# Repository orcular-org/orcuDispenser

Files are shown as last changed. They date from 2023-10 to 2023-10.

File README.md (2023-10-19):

# orcuDispenser

## Liquid dispenser from recycled plastics

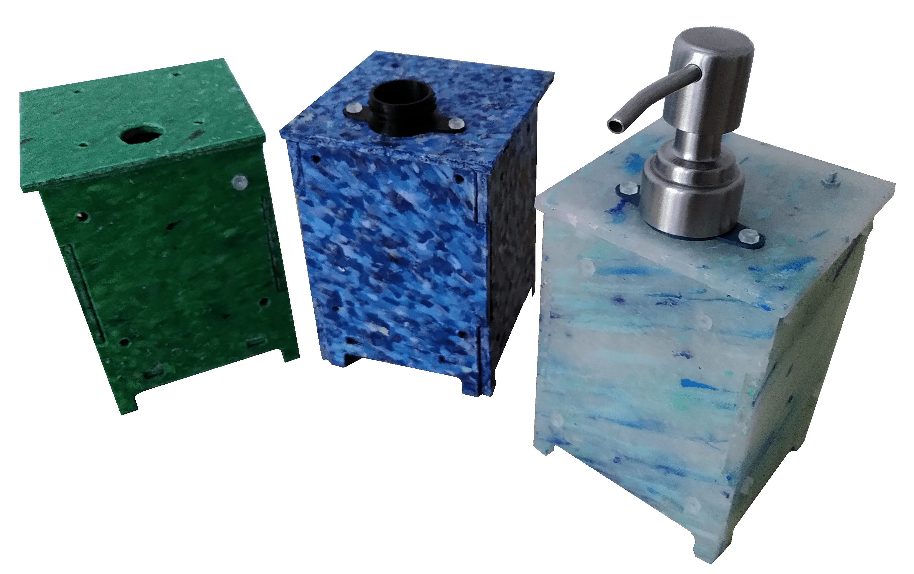
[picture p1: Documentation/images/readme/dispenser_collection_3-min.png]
 

The orcuDispenser (short for "[Orcular](#about-the-orcular-project) Dispenser") is an open-source dispenser made from recycled plastics. The main features are:
- For soap or other liquids like dishwashing liquid, shampoo or body wash
- Made from recycled plastics ([Precious Plastic](https://preciousplastic.com/) sheets)
- Laser-cut parts
- 3D printed parts
- Circular design
  - Easy to repair & upgrade
  - Designed for disassembly
  - All parts recyclebale (except for the pump, depends on the product)
- [Open-source hardware](#license)
- Designed in [FreeCAD](https://www.freecad.org/) (open-source software)
  - CAD file accessible in this repository
  - Parametric design (other sizes are easy to generate)

## 3D view

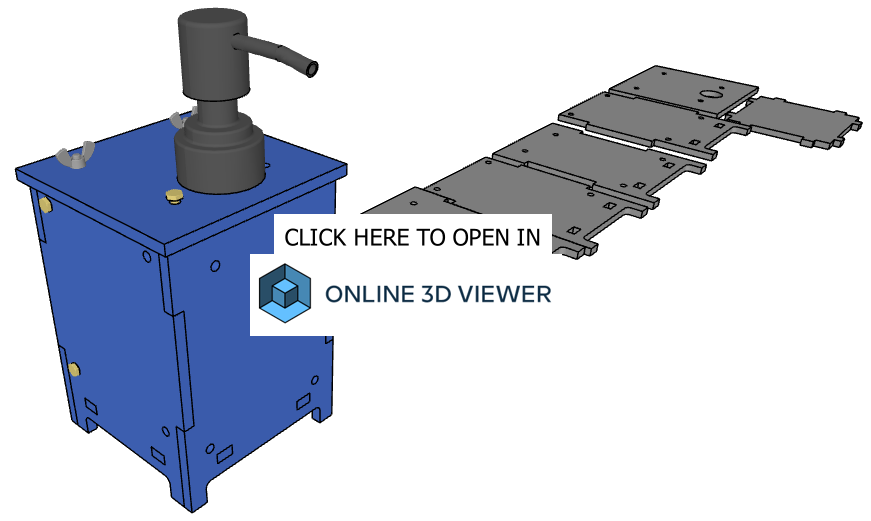
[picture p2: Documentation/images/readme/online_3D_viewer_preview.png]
[](https://3dviewer.net/embed.html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,-245.07455,234.76594,244.75676,161.15922,-120.84555,0.00000,-0.00000,1.00000,45.00000$cameramode=perspective$envsettings=fishermans_bastion,off$backgroundcolor=255,255,255,255$defaultcolor=200,200,200$edgesettings=on,0,0,0,84)

- Please be patient and wait about a minute to load the online 3D view

Controls:
- On computer: Use the left mouse button to rotate, the right mouse button to pan and the mouse wheel to zoom
- On smartphones: Swipe to rotate, use two fingers to zoom and pan 

- Alternative 3D view with more tools [here](https://3dviewer.net/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)
  - Click "Set Z axis as up vector" for better display a 
  - You can hide/show parts and groups on the left-hand side
  - For a complete view of the 3D file, download the [CAD file](CAD) and open it in [FreeCAD](https://www.freecad.org/)
 
## Building instructions
 
For making and building instructions, see the [documentation](Documentation/Introduction.md)

or go directly to:

- 🛒 [Shopping list](Documentation/Shopping_list.md)
- ♻️ [Making sheets from recycled plastics](Documentation/Making_sheets.md)
- 🖨️ [3D printing](Documentation/3D_printing.md)
- 🔫 Laser cutting *(coming soon)*
- 🛠️ [Assembly](Documentation/Assembly.md)
- 🔼 Modding and upgrades *(coming soon)*

## About the Orcular project
The orcuDispenser is part of the Orcular project - https://www.orcular.org

"Orcular" stands for **O**pen Source + Ci**rcular** Economy

The project is about design concepts for locally recyclable products - for a constantly growing open source product library and the development of inner-city production.

Most components can be recycled into new parts - all within one city.
Recyclable plastic parts from the laser cutter, 3D printer and CNC mill, supplemented by standard parts.

## License

The orcuDispenser hardware design, CAD files, BOM, and relative files are are released under the following open source license:

- [CERN Open Hardware Licence Version 2 Weakly Reciprocal - CERN-OHL-W](https://cern-ohl.web.cern.ch/)

The orcuDispenser documentation, assembly manual, pictures and presentation text of this repository are released under the following license:

- [Creative-Commons-Attribution-ShareAlike 4.0 International - CC BY-SA 4.0](http://creativecommons.org/licenses/by-sa/4.0/)

**Author:** Oskar Lidtke, https://github.com/orcular-org/

<br />Except where otherwise noted, this work is licensed under a <a rel="license" href="http://creativecommons.org/licenses/by-sa/4.0/">Creative Commons Attribution-ShareAlike 4.0 International License (CC BY-SA 4.0)</a>.

See best practices for [attribution](https://wiki.creativecommons.org/wiki/Best_practices_for_attribution) and [marking your own work](https://wiki.creativecommons.org/wiki/Marking_your_work_with_a_CC_license) with a CC license.

<p align="left">
<i> <sub> Open Source Hardware logo, <a href="https://creativecommons.org/licenses/by-sa/4.0/">CC BY-SA</a> - <a href="https://www.oshwa.org/open-source-hardware-logo/">Source</a> </sub></i>
</p>



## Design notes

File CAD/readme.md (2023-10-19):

**Recent version: 1.0** - released on October 19, 2023.

The CAD model was designed in FreeCAD. You can download this free and open-source software on https://www.freecad.org

For modding instructions and changing parameters in the CAD file, see the [documentation](../Documentation/Introduction.md), section **Modding and upgrades**.

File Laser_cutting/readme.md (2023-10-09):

This folder contains the laser cutting vector graphics file. For laser cutting instructions, see the [documentation](../Documentation/Introduction.md), section **Laser cutting**.

This SVG vector graphics file was created for 4.7 mm thick sheets. It may also work with uneven sheets within the tolerance range of about 4.2 to 5.2 mm (testing needed).

For instructions about how to generate vector graphics for other sheet thicknesses, see the [documentation](../Documentation/Introduction.md), section **Modding and upgrades**.

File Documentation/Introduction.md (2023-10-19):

> Back to [main page (readme)](../README.md)

# orcuDispenser documentation

## Introduction

> Add introduction text

- 🛒 [Shopping list](Shopping_list.md)
- ♻️ [Making sheets from recycled plastics](Making_sheets.md)
- 🖨️ [3D printing](3D_printing.md)
- 🔫 Laser cutting *(coming soon)*
- 🛠️ [Assembly](Assembly.md)
- 🔼 Modding and upgrades *(coming soon)*

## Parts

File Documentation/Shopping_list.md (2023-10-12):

> Back to [documentation introduction](Introduction.md)

# Shopping list

## Standard parts

Here is a list of standard parts:

| Quantity  | Part | Material | Standard | Shop link (suggestion) |
|---|---|---|---|---|
| 16 | M3 x 10 screw | PP (Polypropylene) | DIN 933/931 / DIN EN ISO 4017 | [Link](https://www.kunststoffschraube.de/product_info.php?products_id=4129) |
| 16 | M3 nut | PP (Polypropylene) | DIN 555/934 / DIN EN ISO 4032 | [Link](https://www.kunststoffschraube.de/product_info.php?products_id=4185) |
| 2 | M3 x 16 screw | Stainless steel | DIN 933 / DIN EN ISO 4017 | [Link](https://www.schraubenking-shop.de/M3-x-16mm-Sechskantschrauben-DIN-933-Vollgewinde-Edelstahl-A2-P000418) |
| 2 | M3 nut | Stainless steel | DIN 934 / DIN EN ISO 4032 | [Link](https://www.schraubenking-shop.de/M3-Sechskantmuttern-DIN-934-Edelstahl-A2-P000447) |
| 2 | M3 wingnut | Stainless steel | DIN 315 or similar | [Link](https://www.schraubenking-shop.de/M3-Fluegelmutter-amerik-Form-Edelstahl-A2-P004284) |

<table>
  <tr>
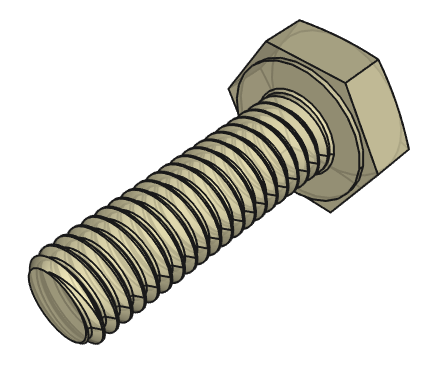
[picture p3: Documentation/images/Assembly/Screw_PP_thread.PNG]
    <td></td>
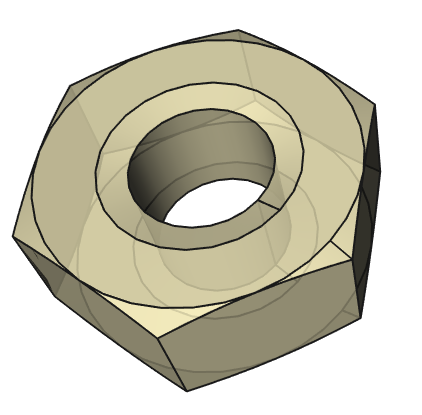
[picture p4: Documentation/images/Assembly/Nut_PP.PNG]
    <td></td>    
  </tr>
  <tr>
    <td>M3 x 10 screw <br> Polypropylene (PP) <br> 18 pieces</td></td>
    <td>M3 nut <br> Polypropylene (PP) <br> 18 pieces</td>
  </tr>
</table>

<table>
  <tr>
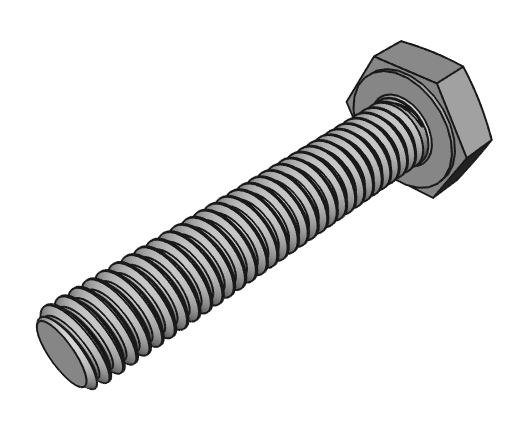
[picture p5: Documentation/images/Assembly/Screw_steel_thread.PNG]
    <td></td>
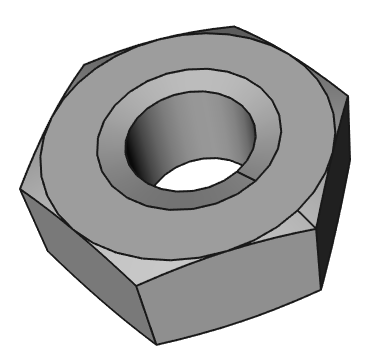
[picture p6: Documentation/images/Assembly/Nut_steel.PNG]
    <td></td>
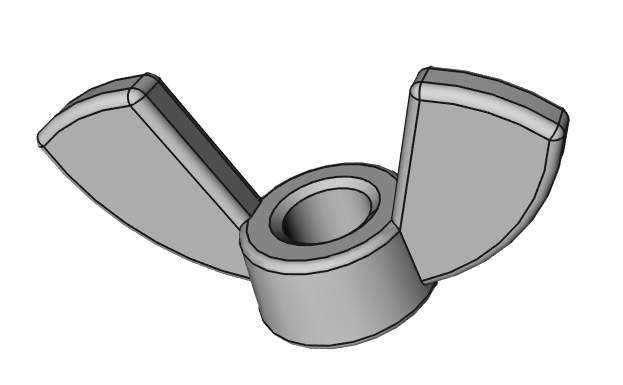
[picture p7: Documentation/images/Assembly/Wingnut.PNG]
    <td></td>
  </tr>
  <tr>
    <td>M3 x 16 screw <br> Stainless steel <br> 2 pieces</td>
    <td>M3 nut <br> Stainless steel <br> 2 pieces</td>
    <td>M3 wingnut <br> Stainless steel <br> 2 pieces</td>
  </tr>
</table>

- Most of the screws and nuts are suggested to be made from Polypropylene (PP). The reasons are:
  - PP is lighter than steel, which makes the whole dispenser lighter
  - PP is recyclebale in plastic recycling machines and PP is the same material that the sheets are made from. This way, broken or used PP screws and nuts can be recycled and new sheets can be made from the PP material.
  - PP parts have a nice translucent look, they are not so visible and don't stand out too much
  - But you can still use steel screws and nuts instead of PP if you like

- The two M3 x 16 screws, nuts and wingnuts in the lid should be stainless steel. The reasons are:
  - These wingnuts have to be undone every time you want to refill your dispenser. Plastic screws and nuts tend to wear off and break quickly, so steel parts are recommended
  - Stainless steel is recommended as these parts may get in contact with water a lot (by splashes from the water tap or wet hands)
 
- All screws should be hex head screws so that they fit into the pockets of the 3D printed parts

## Other parts

Here is a list of other parts:

| Quantity  | Part | Shop link (suggestion) |
|---|---|---|
| 1 | Soap dispenser pump | [Link](https://www.amazon.de/Ertisa-Edelstahl-seifenspender-flüssiges-Badezimmer/dp/B086PS4G4Q/) |

- If the suggested pump is not available, get a similar one or reuse a pump from another dispenser. Just make sure that it fits on the thread.

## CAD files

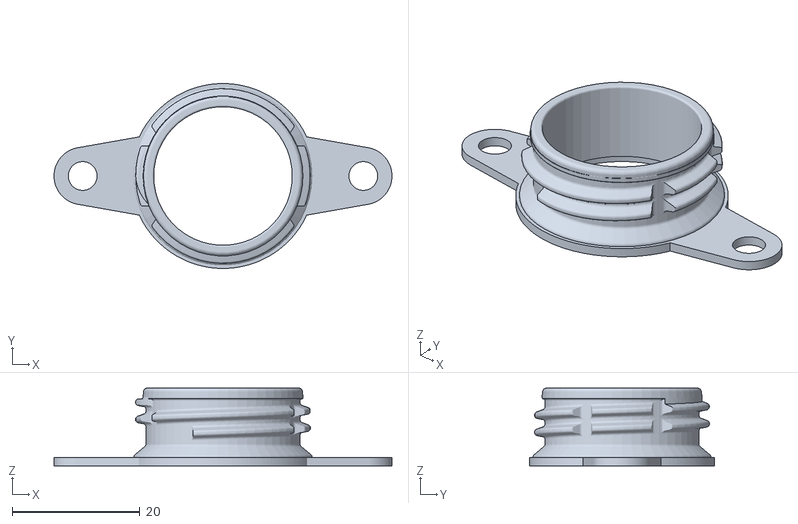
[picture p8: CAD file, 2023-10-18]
3D_printing/Adapter_for_pump.stl
53.0 x 29.0 x 12.2

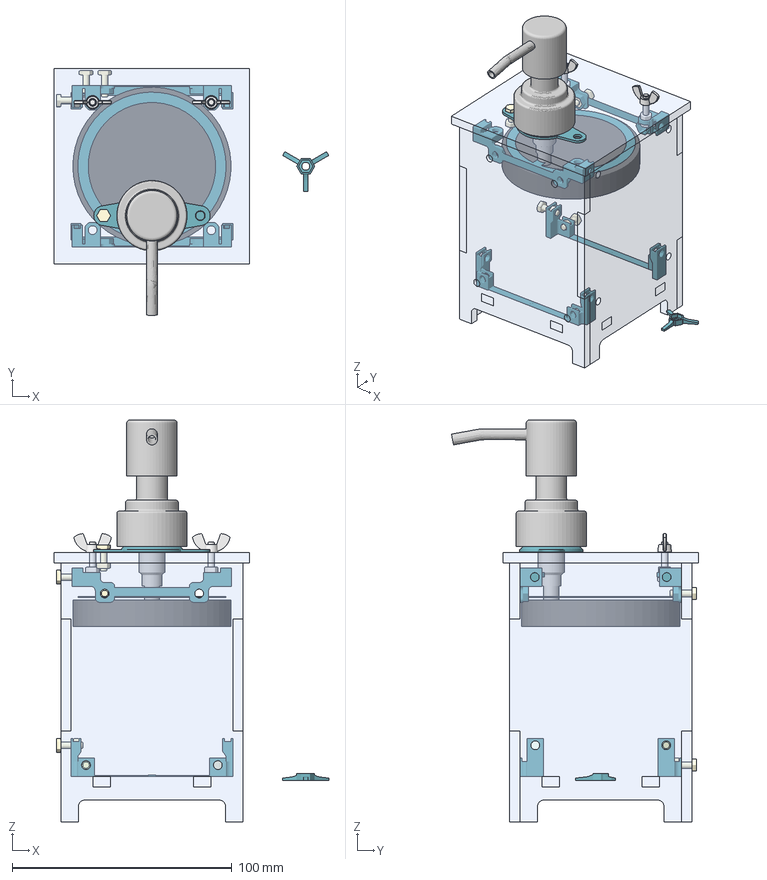
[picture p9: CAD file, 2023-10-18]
CAD/orcuDispenser_v_1_0.FCStd
125.0 x 112.5 x 183.0 mm
Bottom
Front
Back
Side_Left
Side_Right (clone)
Lid
3DP_Angle_bracket_Bottom
3DP_Angle_bracket_Bottom (Mirror #1)
Connector_bottom
3DP_Angle_bracket_Top
3DP_Angle_bracket_Top (Mirror #2)
Connector_top
3DP_Wrench
3DP_Drilling_template
M3x10-Screw
M3-Nut
M3x10-Screw001
M3x10-Screw002
M3x10-Screw003
M3-Nut006
M3-Nut007
M4-Nut001
M3x10-Screw004
M3-Nut005
M3_screw_right
M3_nut_right
Wingnut_right
Pump
Pipe
Jar (0,2 L)
Jar_Lid
3DP_Adapter_for_pump
Angle_bracket_bottom
Angle_bracket_top

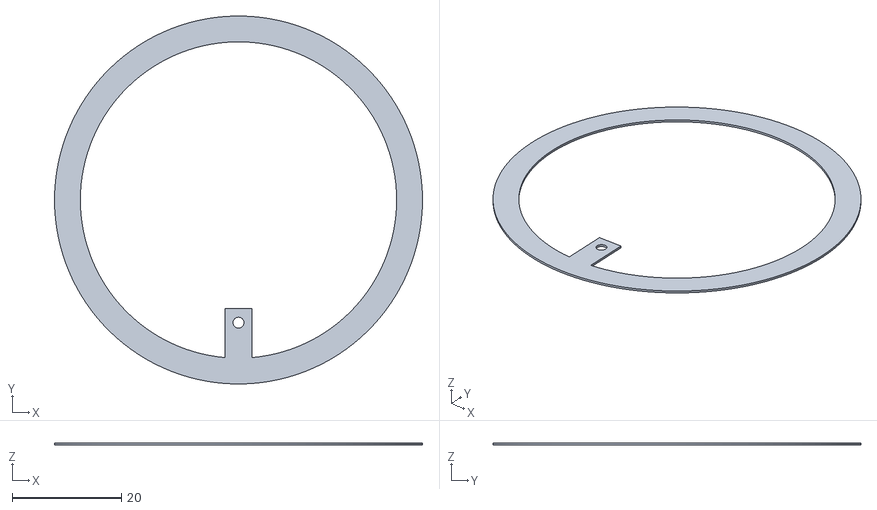
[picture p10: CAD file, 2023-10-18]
3D_printing/Drilling_template.stl
67.5 x 67.5 x 0.4

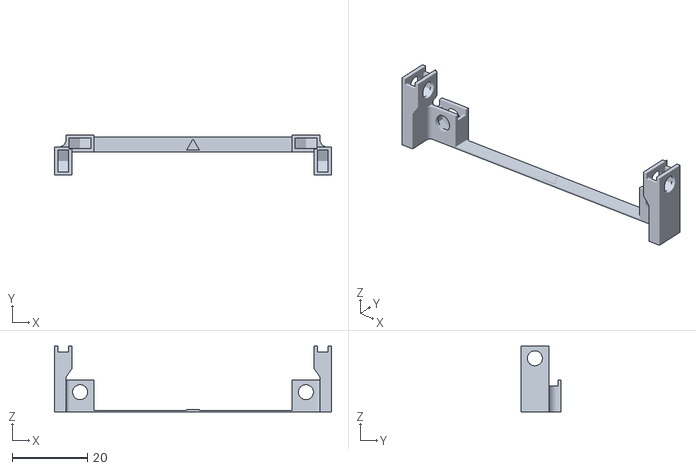
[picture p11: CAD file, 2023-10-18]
3D_printing/Angle_bracket_bottom.stl
73.6 x 10.8 x 17.4

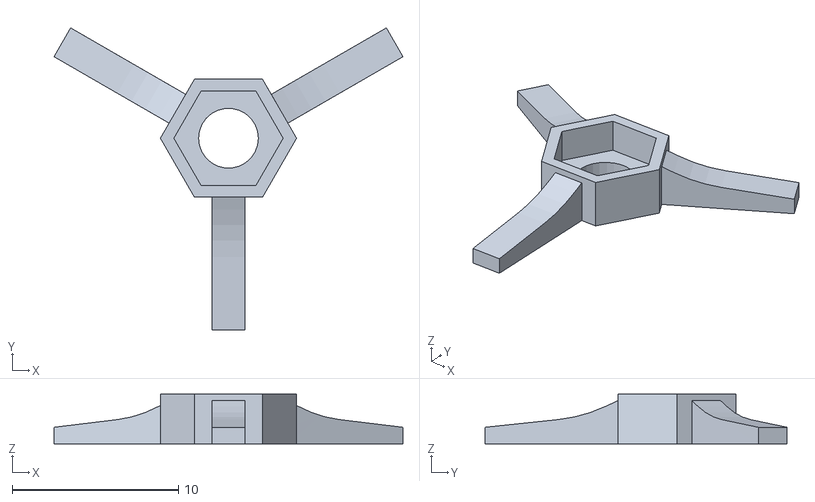
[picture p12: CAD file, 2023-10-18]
3D_printing/Wrench.stl
21.0 x 18.2 x 3.00

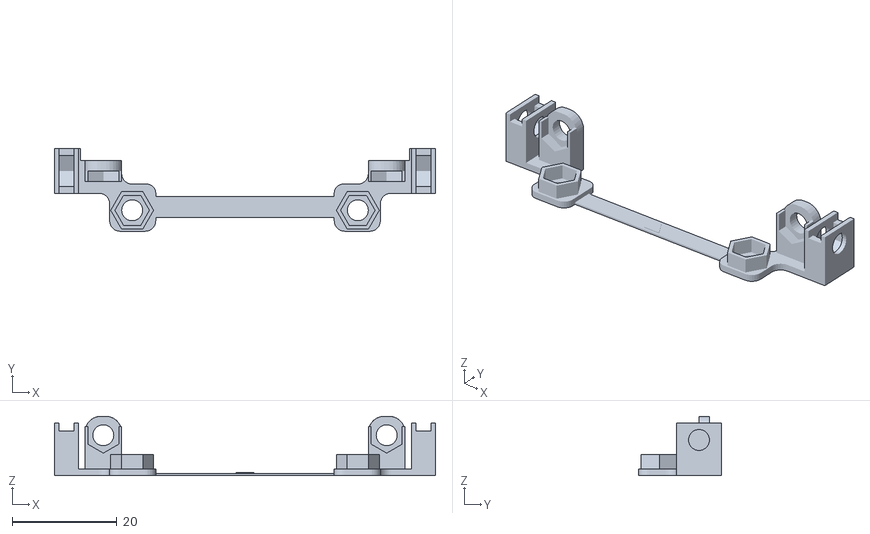
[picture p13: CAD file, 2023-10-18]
3D_printing/Angle_bracket_top.stl
72.6 x 15.7 x 11.3

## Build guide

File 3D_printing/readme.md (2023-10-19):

This folder contains all 3D printing STL files. For printing instructions, see the [documentation](../Documentation/Introduction.md), section [3D printing](../Documentation/3D_printing.md).

You can click on any STL file to see a 3D view (GitHub feature).

"Adapter_for_pump.stl" was created using "Pop Bottle Thread" from [this Thingiverse file](https://www.thingiverse.com/thing:3527583) (license: CC0 / public domain, no attribution required).

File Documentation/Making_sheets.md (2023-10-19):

> Back to [documentation introduction](Introduction.md)

# Making sheets from recycled plastics

Here are some instructions for making sheets from recycled plastic using [Precious Plastic](https://preciousplastic.com/) methods.

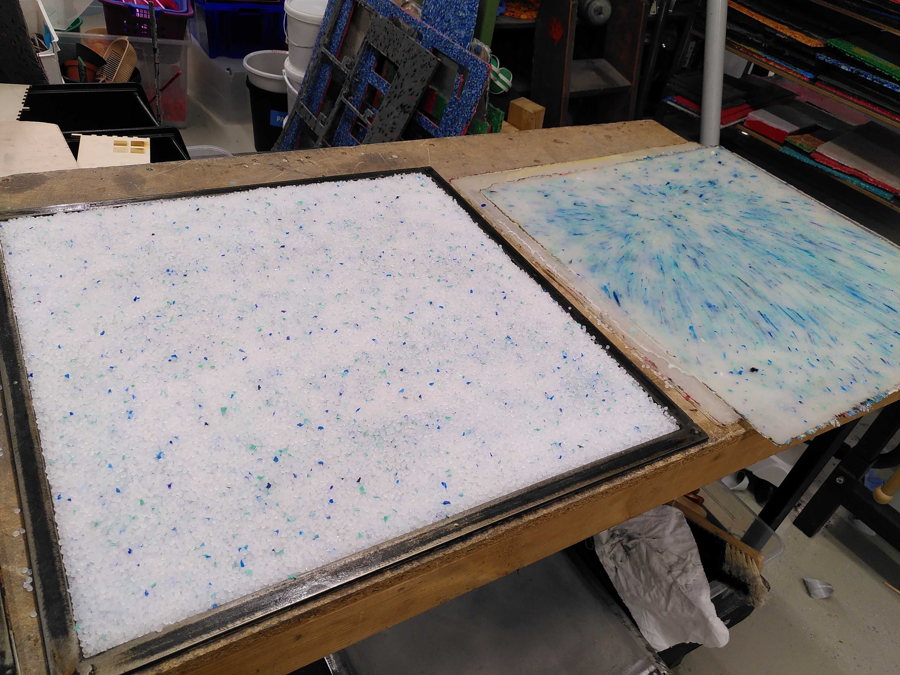
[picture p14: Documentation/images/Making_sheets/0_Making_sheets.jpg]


## Tools and machines needed

- Plastic shredder (like the [Precious Plastic shredder](https://community.preciousplastic.com/academy/build/shredderpro) or similar)
- Plastic sheet press (like the [Precious Plastic sheet press](https://community.preciousplastic.com/academy/build/sheetpress) or similar)
  - Optional: Cooling press

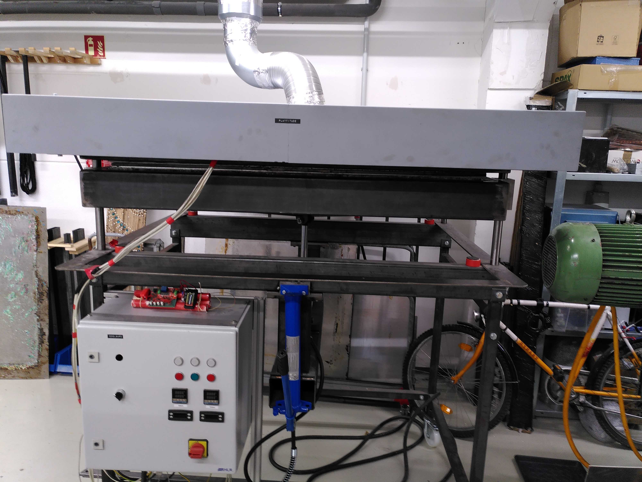
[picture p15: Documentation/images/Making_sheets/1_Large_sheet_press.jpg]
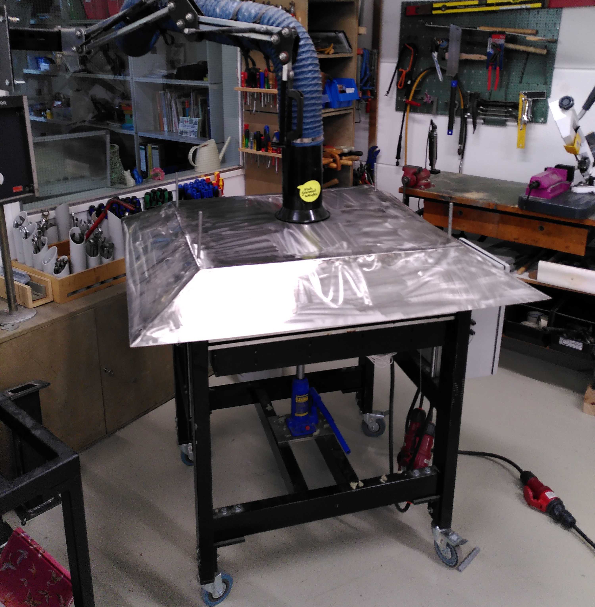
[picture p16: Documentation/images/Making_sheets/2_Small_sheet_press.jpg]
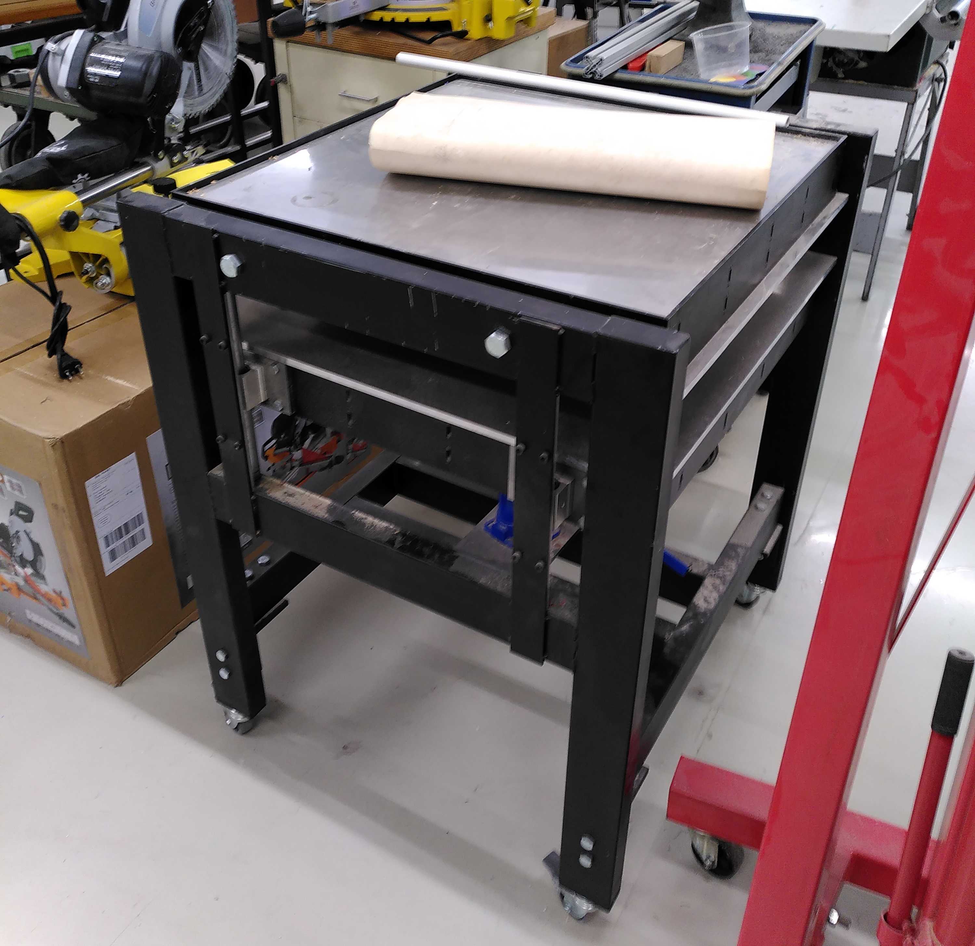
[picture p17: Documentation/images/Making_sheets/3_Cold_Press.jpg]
  

_Images above: Large sheet press (1 x 1 m) - Small sheet press (60 x 60 cm) - Cooling press (60 x 60 cm)_

## Material

There are many types of plastics that can be recycled using Precious Plastic methods. However, it is recommended to use **PP (polypropylene)**, because PP is particularly suitable for laser cutting.

## Shredding

Make sure to use only PP (polypropylene) plastics and don't mix it with any other types of plastics.

## Using purchased plastics

If you don't have enough PP plastic for recycling, you can still purchase PP (polypropylene) from online shops. It's hard to find shops for colored PP pellets, but colorless (white/translucent) PP pellets are quite common and can be purchased from many online shops.

## Pressing sheets

The sheets should have a thickness of about 4.7 mm. This way you can use the standard SVG file (vector graphics) for laser cutting provided in this repository. But you can still generate SVG vector graphics for other thicknesses (read more in the [documentation](Introduction.md), section Modding and upgrades).

Sheets with a thickness of 4 to 5 mm should work well, too. When using sheets with more than 5 mm you might get trouble with laser cutting them.

### Example calculation for sheet mould and plastic weight

> :warning: This is an example calculation for a specific mould. If your mould has different dimensions, adjust the calculation accordingly.

A mould measuring 560 x 560 x 4 mm was used for the prototype. So the mold had a thickness of 4 mm.
However, due to some inaccuracies, sheets came out more like 4.5 to 5 mm thick.

First you should calculate the weight of the plastic you need. In this example:
- Volume = 56 x 56 x 0.4 cm =  1254.4 cm³
- Density of PP = 0.93 g/cm³
- Weight = Volume x Density = 1254.4 cm³ x 0.93 g/cm³ = 1166.59 g
- Adding 5 % : 1166.592 g x 1.05 = 1224.92 g
  - Experience shows that the calculated amount is often not quite enough and you should add about 5 %

This example therefore results in a weight of about **1225 g**.

If you mix different colors, the sum should be 1225 g. For example, the white sheets with blue and turquoise sprinkles (as seen in the images) was mixed from:
- 1185 g white
- +20 g blue
- +20 g turquoise
  - adds up to 1225 g
 
Depending on your machine and process, these values may also vary. Several attempts should be made to determine the correct weight.

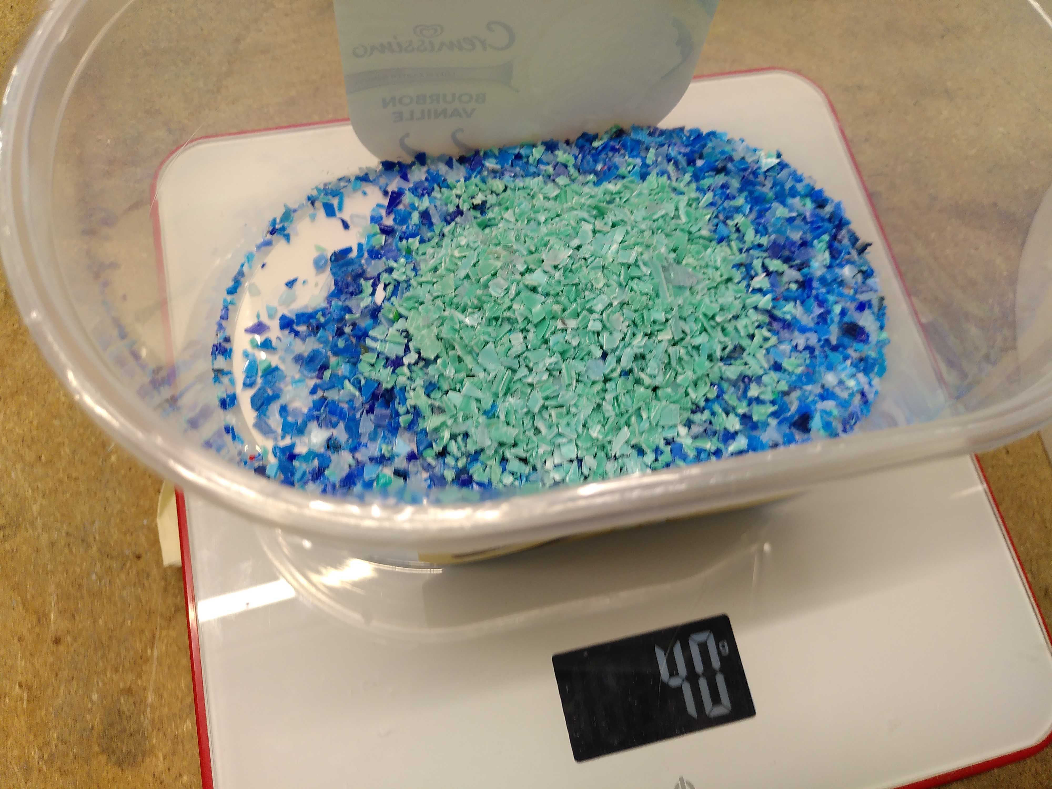
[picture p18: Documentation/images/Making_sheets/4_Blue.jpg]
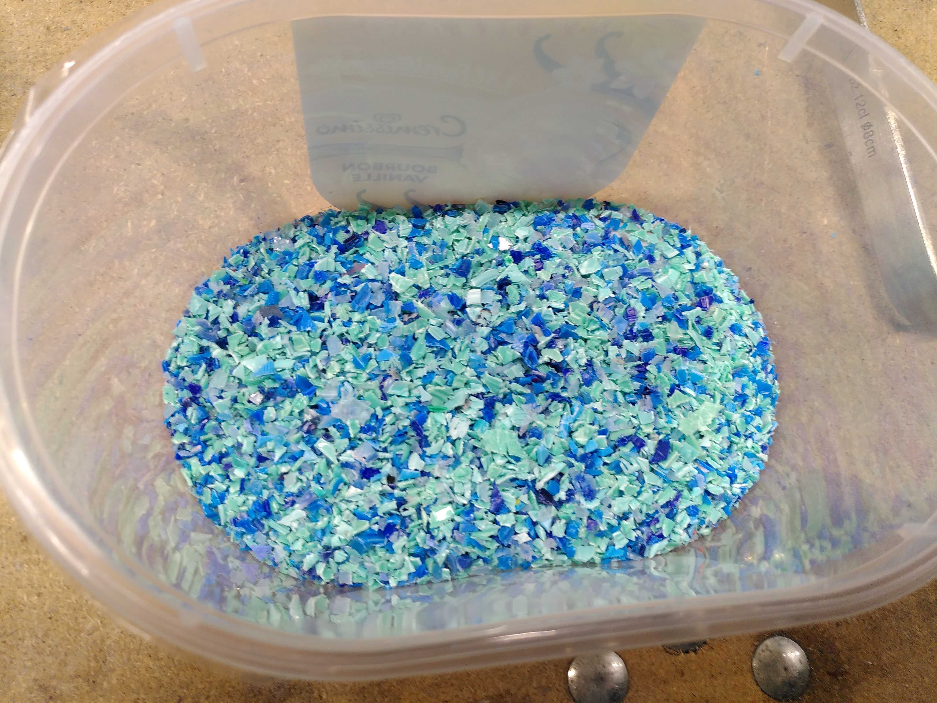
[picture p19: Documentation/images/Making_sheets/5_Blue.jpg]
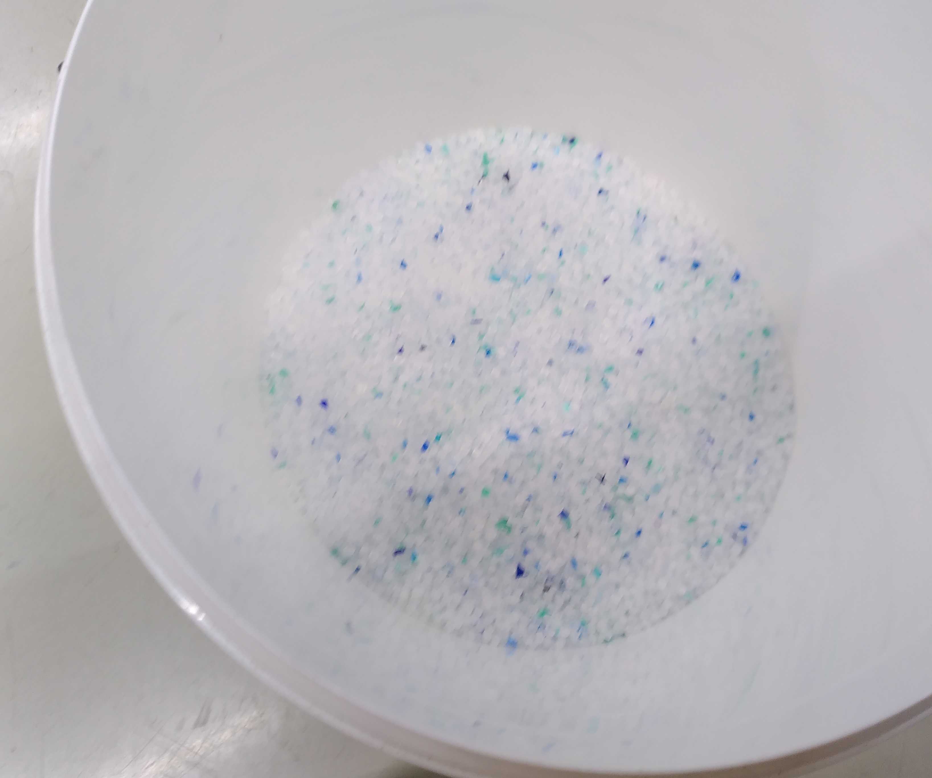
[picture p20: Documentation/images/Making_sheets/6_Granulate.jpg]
  

### Making the sheet

- If you used different colors, mix them well in a bucket
- Apply some silicon grease on the bottom of the mould
- Pour in the plastic granulate in the mould and level it

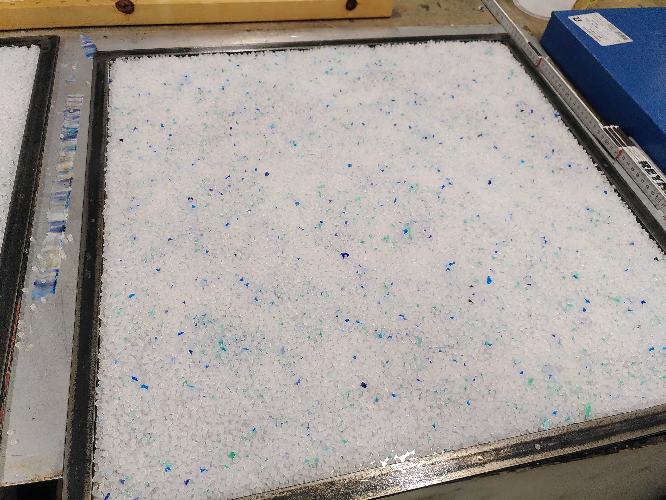
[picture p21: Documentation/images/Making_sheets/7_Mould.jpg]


- Put a metal sheet on top of it
- Place the mould with the plastic in your sheet press
- Raise the lower plate by using the jack (depends on your machine) until the top metal sheet barely touches the top side of the sheet press
- Preheat it to 230 °C (recommended temperature for PP by Precious Plastic)
- Wait until the temperature reaches 230 °C
  - Apply some more pressure using the jack
- Wait 10 mins
  - Apply some more pressure using the jack
  - Repeat this process two more times
  - After the 4th time of adding pressure, let it heat 10 more mins
> ℹ️ This procedere makes sure that you wont't have any air bubbles inside your sheet
- After adding pressure four times, heating 10 more mins and therefore 40 mins of baking you can turn off the heating
- For cooling down there are two options:
  - Let the sheet cool down for at least 6 hours (depends on your machine and the environment) in the sheet press (if you don't have a cooling press)
  - If you have a cooling press, you can move the sheet to the cooling press, apply pressure and let it cool down for at least 6 hours (depends on your machine and the environment)
- Remove the mould from the press and take out the sheet

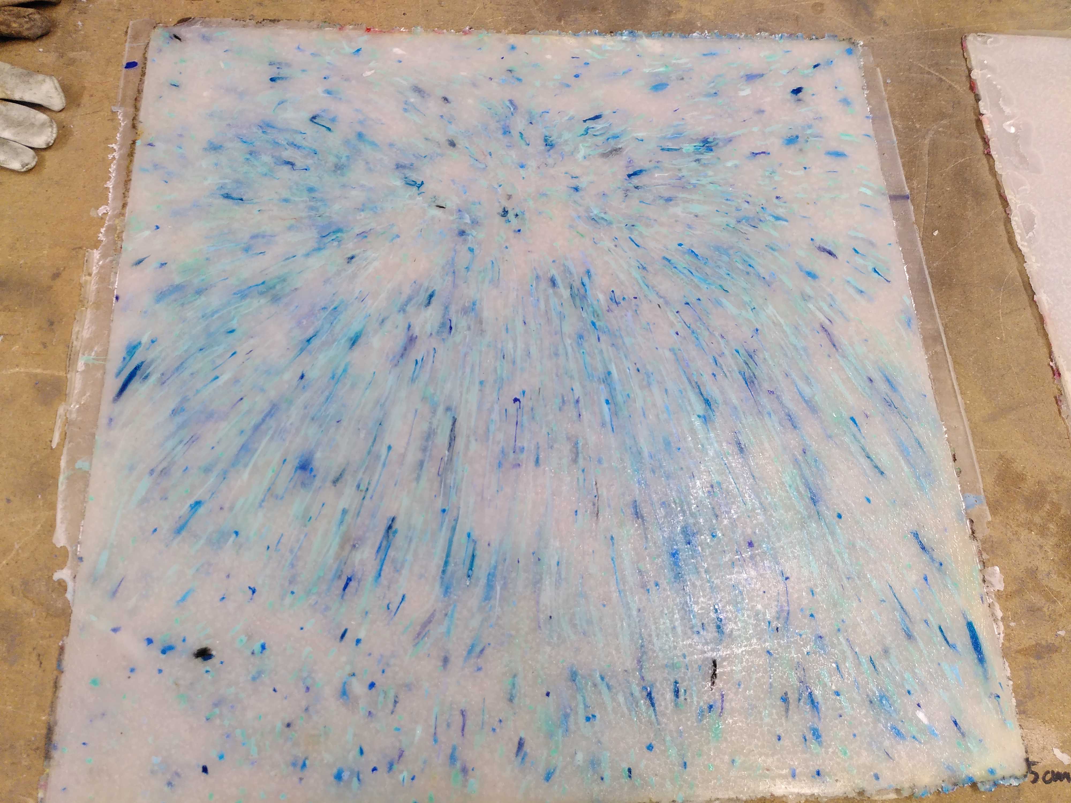
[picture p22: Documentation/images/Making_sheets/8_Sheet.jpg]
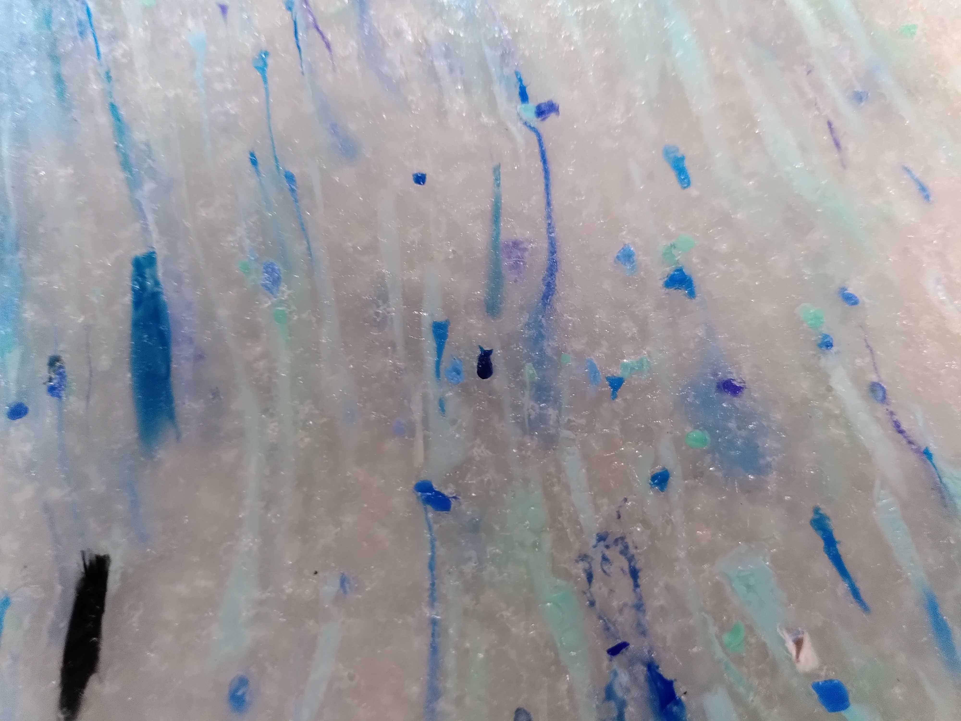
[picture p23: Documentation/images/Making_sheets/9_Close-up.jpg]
 

## Postprocessing

- If your sheet feels greasy from the silicone, use some dish soap or vinegar to remove the grease and wash it off with water
- Cut off the edges with a table saw or utility knife
- Measure the thickness at different points on the edge. If it is around 4.0 to 5.5 mm thick, it should be okay, but if it varies more than 0.5 mm, it could cause difficulties in the laser cutting process.
- Examine your sheet on both sides and check if it has any air bubbles. Small air bubbles should be okay, but larger air pockets or cavities should be avoided in the laser cutting.

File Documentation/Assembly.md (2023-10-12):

> Back to [documentation introduction](Introduction.md)
# Assembly

## Part list

Make sure you have all the parts:
- 3D printed parts (list [here](Introduction.md), section 3D printing)
  - 5 parts for the dispenser (3D printed)
  - 1 wrench tool (3D printed, see image below)
  - 1 drilling template (3D printed)
- Laser cut parts (list [here](Introduction.md), section laser cutting)
  - 6 parts (laser-cut)
- Purchased parts (list [here](Introduction.md), section shopping list)
  - Pump with tube
  - Jar with lid
  - Screws and nuts (see images below)

<table>
  <tr>
    <td></td>
    <td></td>
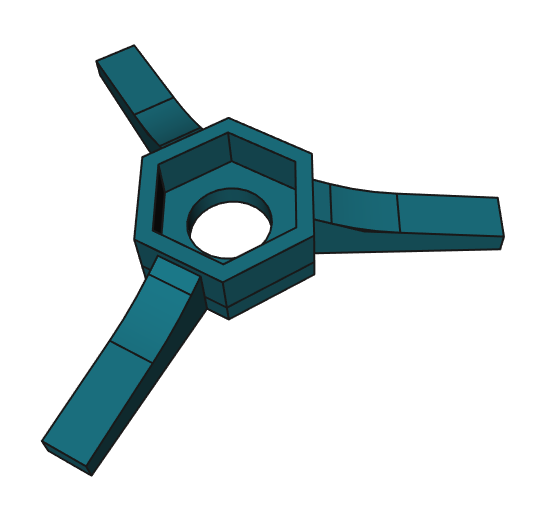
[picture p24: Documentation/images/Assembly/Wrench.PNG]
    <td></td>
  </tr>
  <tr>
    <td>M3 x 10 screw <br> Polypropylene (PP) <br> 18 pieces</td></td>
    <td>M3 nut <br> Polypropylene (PP) <br> 18 pieces</td>
    <td>Wrench (3D printed)</td>
  </tr>
</table>

<table>
  <tr>
    <td></td>
    <td></td>
    <td></td>
  </tr>
  <tr>
    <td>M3 x 16 screw <br> Stainless steel <br> 2 pieces</td>
    <td>M3 nut <br> Stainless steel <br> 2 pieces</td>
    <td>M3 wingnut <br> Stainless steel <br> 2 pieces</td>
  </tr>
</table>

  ## Tool list
Check that you have all the tools you need:
- Small scissors (for removing stringing from the 3D printed parts)
- Large scissors or side cutter (for cutting the pump tube)
- Tweezer (for putting the nuts in the 3D printed part pockets)
- Wrench for M3 nuts or small pliers (for tightening the M3 steel nuts)
- Drilling machine with 8 mm drill (drill size may vary depending on pump purchased)
- File (only needed if the parts are too thick and don't fit together)

## Arranging laser-cut parts

- Examine the six laser-cut parts from recycled plastics. For each part, decide which side you want on the outside of the dispenser (the visible side). Since all parts are symmetrical, they can be flipped to any side.
- Put the lid and bottom away for now and continue with the four side parts
- Decide which parts should be front, back, left and right
  - The **front** and **back** part are identical and can therefore be swapped
  - The **left** and **right** part are identical and can therefore be swapped
 
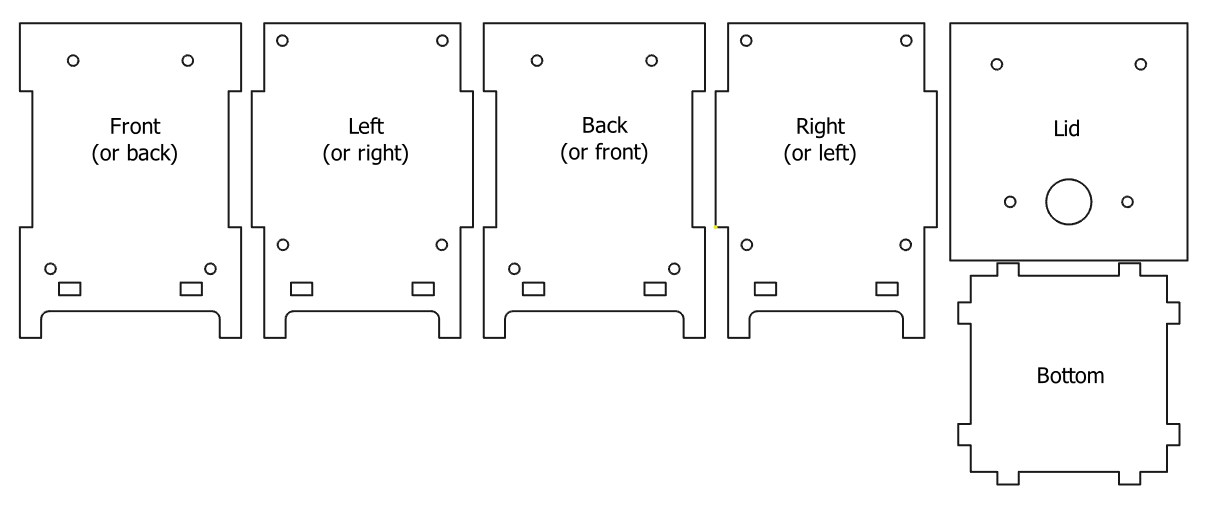
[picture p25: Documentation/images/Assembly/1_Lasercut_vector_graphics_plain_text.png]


- Arrange the six side parts and the bottom part as seen in the picture below

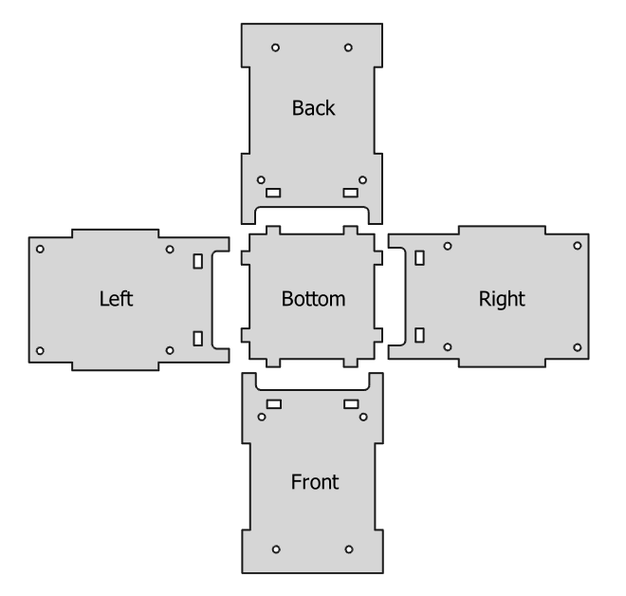
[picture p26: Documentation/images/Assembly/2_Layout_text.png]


- Make a test assembly by putting the five parts together (without using screws or nuts for now). Check if the parts fit together
  - A tight fit is ideal, but if they are a little bit loose, it's still okay
  - If the parts are too thick and can't be pushed-in, you may try to process the parts a bit using a file or laser-cut one or several parts again from another sheet
- When done with the test assembly and everything fits fine, disassamble the parts and rearrange them as in the picture above, so you will remember which part is front/back/left/right
- Leave the laser-cut parts for now and continue with the 3D printed parts

## Putting nuts and screws in the 3D printed angle brackets

- Examine all 3D printed parts and check if there is stringing left from the 3D printing process
  - If so, use some small scissors to cut and remove the strings
  - Be extra careful in the pockets for the nuts so that the nuts fit in well.

 <table>
  <tr>
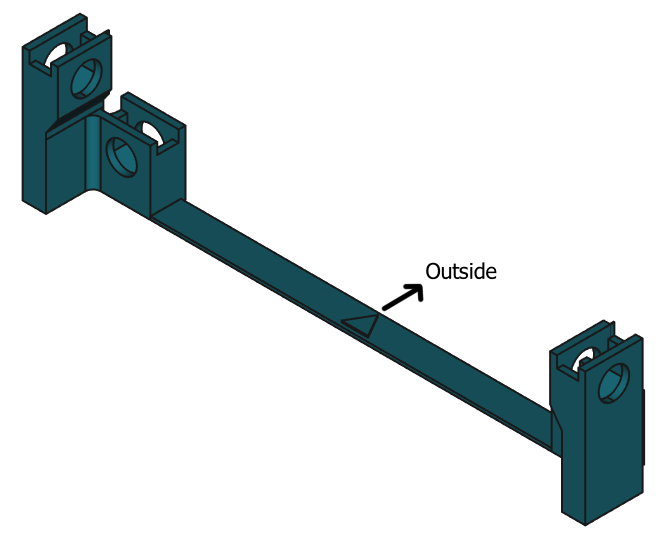
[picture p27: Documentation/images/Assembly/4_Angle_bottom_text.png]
    <td>  </td>
    <td>
      <ul>
        <li>Start with one of the 3D printed <b>bottom angle brackets</b> (there should be two of them)</li>
        <li>The small arrow shows where the outside will be and will help you in the assembly process later</li>
      </ul>
    </td>
  </tr>
</table>

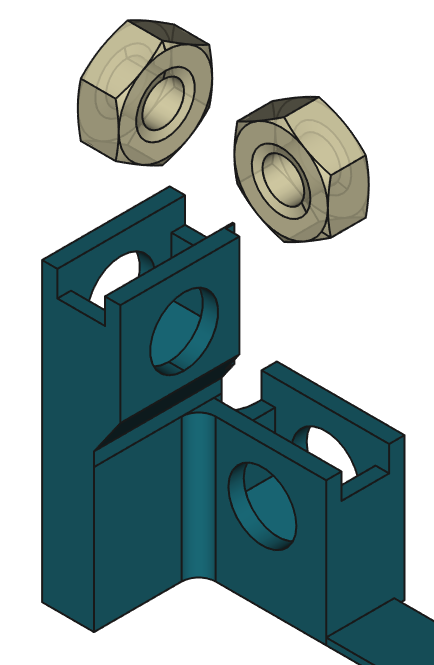
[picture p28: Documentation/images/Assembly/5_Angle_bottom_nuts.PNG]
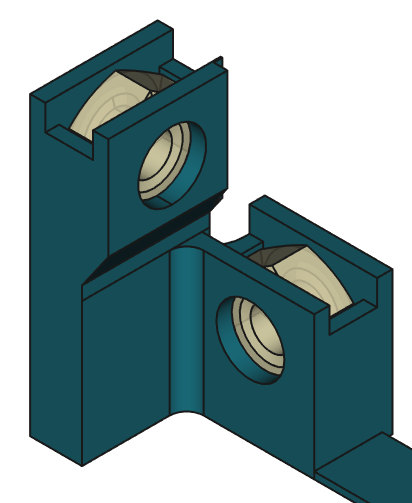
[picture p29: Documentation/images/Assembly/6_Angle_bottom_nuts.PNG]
 <table> <tr> <td>  <br>  </td> <td> <ul>
        <li>Put the M3 nuts (PP) in the pockets</li>
        <li>You can use the tweezer to make it easier</li>
        <li>Make sure the holes of the nuts align with the holes in the pockets (take a look from the outside)</li>
        <li>Put all the nuts in the pockets (4 nuts for each bottom angle bracket)</li>
      </ul> </td> </tr> </table>

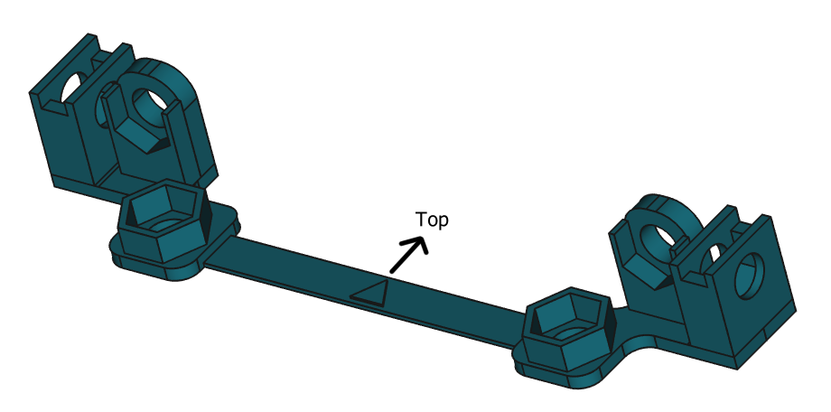
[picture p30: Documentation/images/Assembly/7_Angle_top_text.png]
 <table> <tr> <td>  </td> <td> <ul>
        <li>Continue with one of the 3D printed <b>top angle brackets</b> (there should be two of them)</li>
        <li>The small arrow shows where the top will be and will help you in the assembly process later</li>
      </ul> </td> </tr> </table>

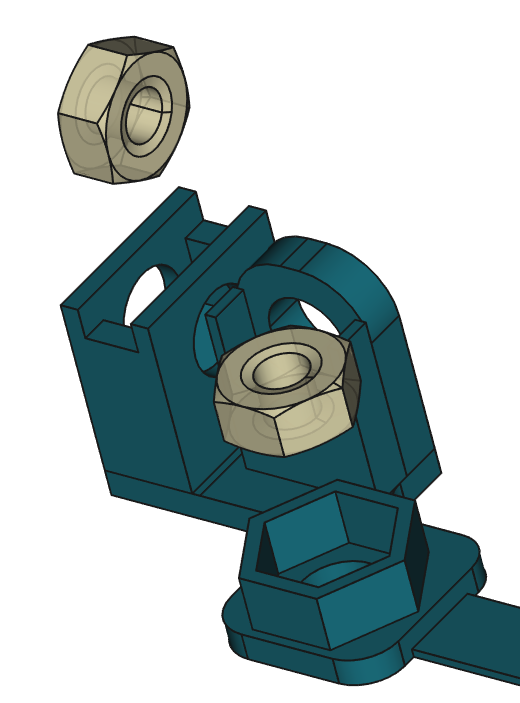
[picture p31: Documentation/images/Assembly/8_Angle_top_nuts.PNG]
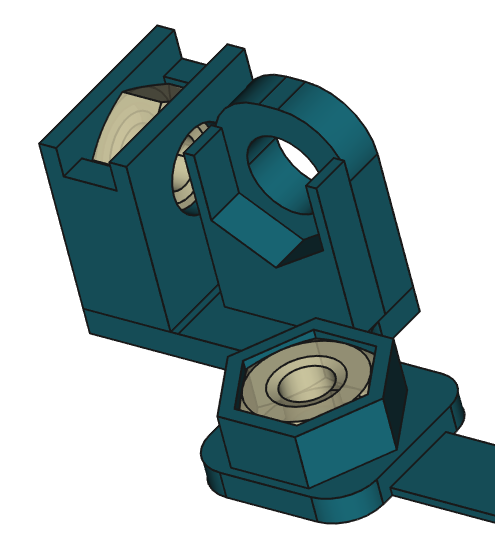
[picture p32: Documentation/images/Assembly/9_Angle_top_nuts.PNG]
 <table> <tr> <td>  <br>  </td> <td> <ul>
        <li>Put the M3 nuts (PP) in the pockets</li>
        <li>Put all the nuts in the pockets (4 nuts for each top angle bracket)</li>
        <li>If you can't push the nut in the hexagonal pocket (the right one in the picture), take a PP screw, put on the nut on the tip of the screw (just turn it a little bit) and push the nut with the screw in the hexagonal pocket. After that, unscrew and take away the screw</li>
      </ul> </td> </tr> </table>

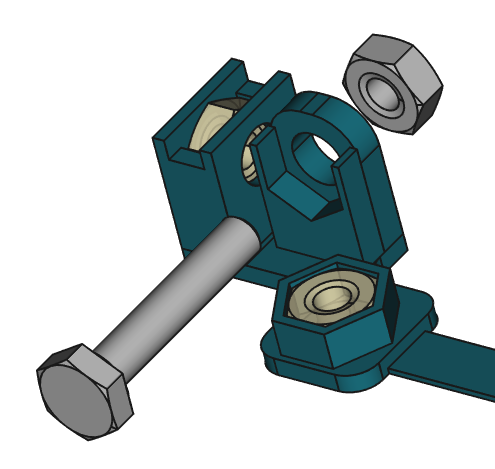
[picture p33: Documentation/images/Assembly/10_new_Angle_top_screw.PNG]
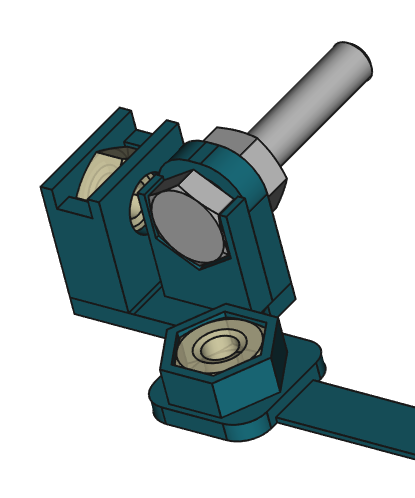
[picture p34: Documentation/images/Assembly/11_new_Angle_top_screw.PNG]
 <table> <tr> <td>  <br>  </td> <td> <ul>
        <li>One of the two top angle brackets should get two steel screws</li>
        <li>Put in the steel screw (M3 x 16) in the pocket and mount a M3 steel nut on it</li>
        <li>Tighten it well (with a wrench or pliers) so the screw sits tight and won't move</li>
      </ul> </td> </tr> </table>

> ____________________________
> 
> ⚠ Note: From this point on, most pictures don't show all the screws and nuts. For simplicity reasons, most screws and nuts are not visible although they might be attached already.
> 
>____________________________

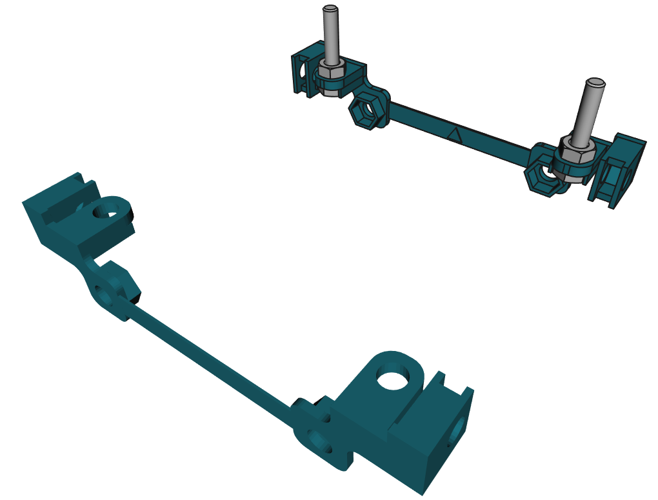
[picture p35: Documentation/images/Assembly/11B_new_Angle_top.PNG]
 <table> <tr> <td>  </td> <td> <ul>
        <li>After that, you should have one top bracket with two steel screws in it (and 4 PP nuts)</li>
        <li>This one will go to the <b>back side</b></li>
        <li>The other top bracket doesn't have steel screws (the holes stay empty), only 4 PP nuts</li>
        <li>This one will go to the <b>front side</b></li>
      </ul> </td> </tr> </table>

## Assembling the four side parts and the bottom part

 <table>
  <tr>
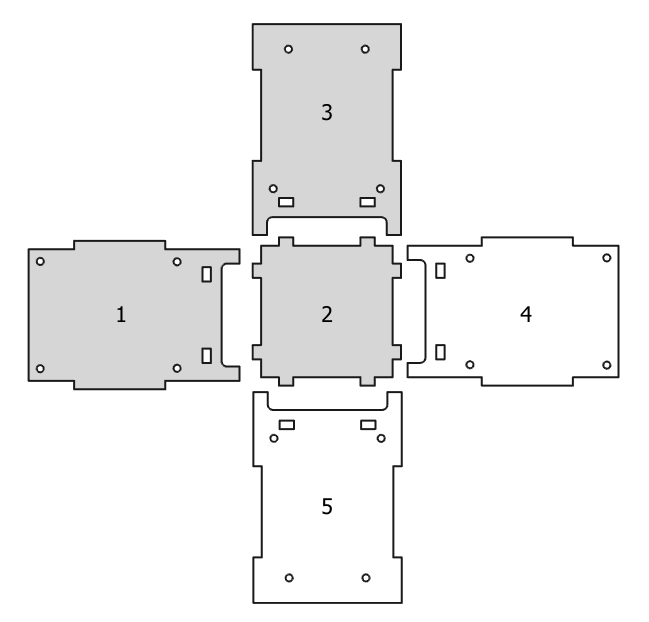
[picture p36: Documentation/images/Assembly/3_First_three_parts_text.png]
    <td>  </td>
    <td>
      <ul>
        <li>The picture on the left shows the recommended order for assembly </li>
        <li>Once the first three parts (left (1), bottom (2) and back (3)) are assembled, the structure should stand and be stable</li>
      </ul>
    </td>
  </tr>
</table>

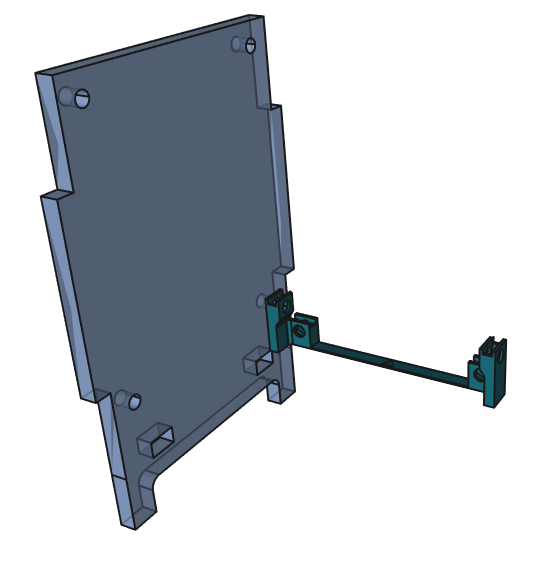
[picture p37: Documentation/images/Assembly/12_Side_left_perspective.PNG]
 <table> <tr> <td>  </td> <td> <ul>
        <li>Start with the left side part (1)</li>
        <li>Mount one <b>bottom bracket</b> (with the M3 PP nuts in it) to the side part</li>
      </ul> </td> </tr> </table>

- Put a M3 x 10 (PP) screw from the outside and tighten it with the 3D printed wrench

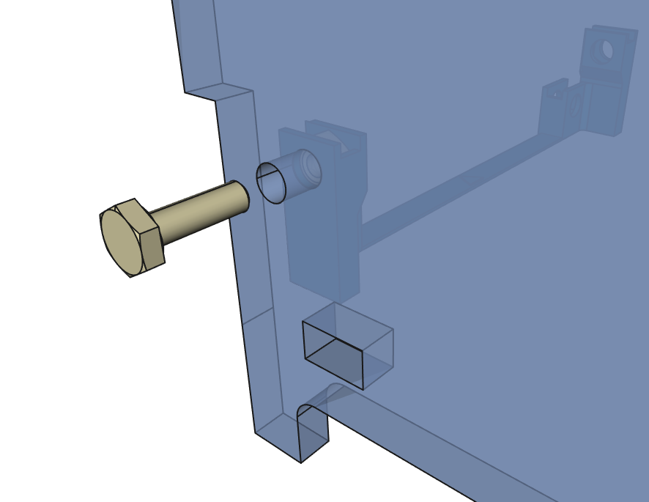
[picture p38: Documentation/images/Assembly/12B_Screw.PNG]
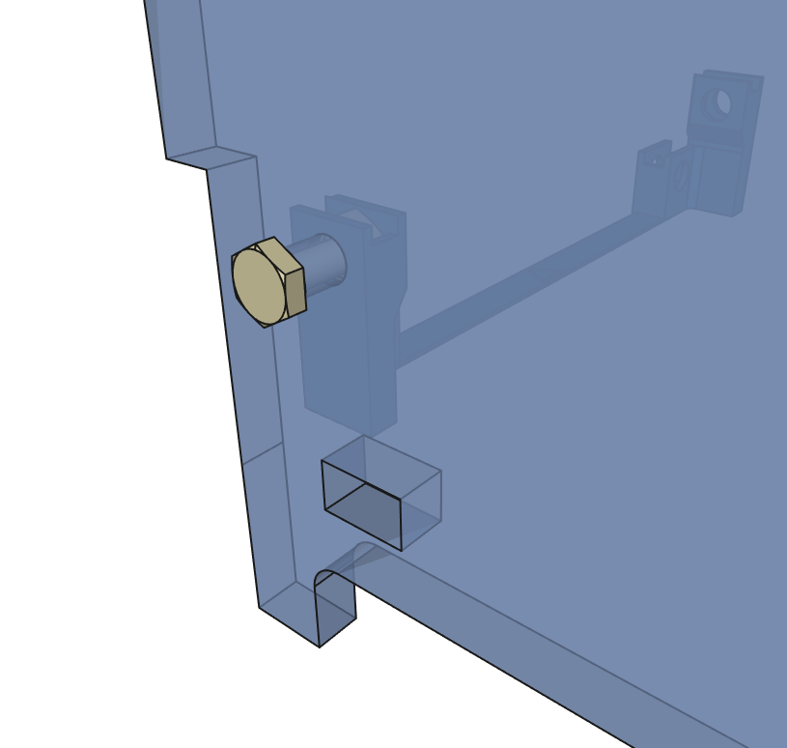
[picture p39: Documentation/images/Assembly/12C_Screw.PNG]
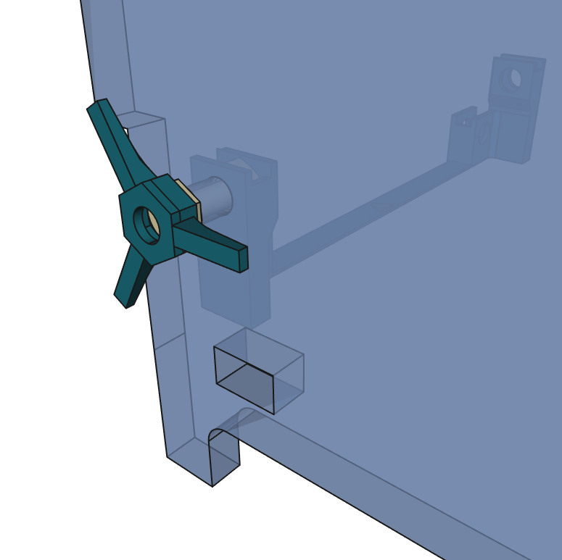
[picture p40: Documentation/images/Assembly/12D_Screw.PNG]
  

- Continue assembling the second **bottom bracket**, the bottom part (2) and the back part (3)
- Use M3 x 10 (PP) screws for connecting the parts and tighten them with the 3D printed wrench

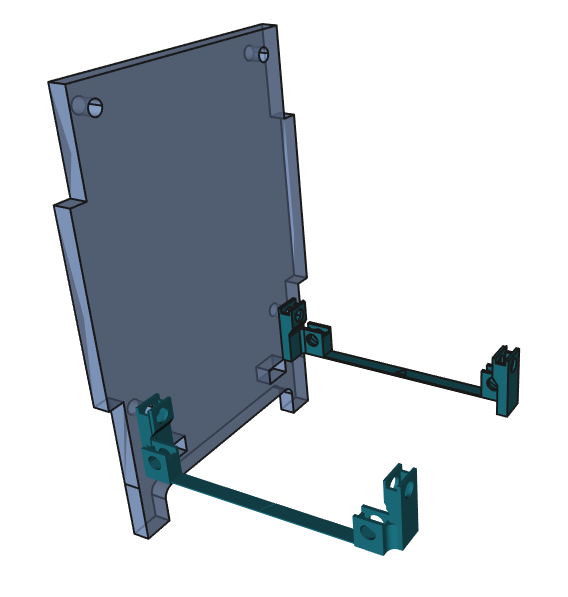
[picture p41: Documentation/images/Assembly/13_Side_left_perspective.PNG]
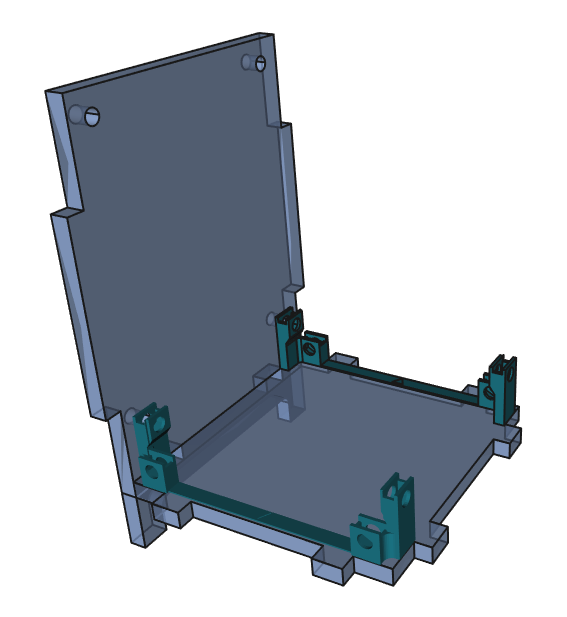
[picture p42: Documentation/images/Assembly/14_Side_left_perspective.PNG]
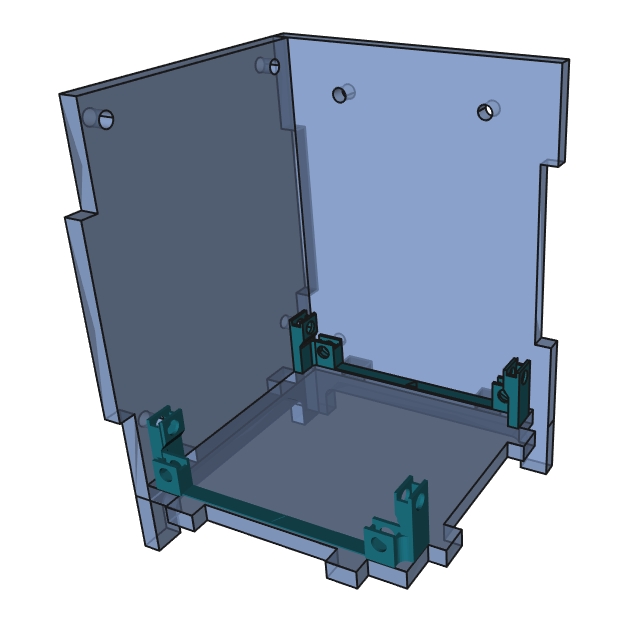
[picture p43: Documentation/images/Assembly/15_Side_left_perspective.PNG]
  

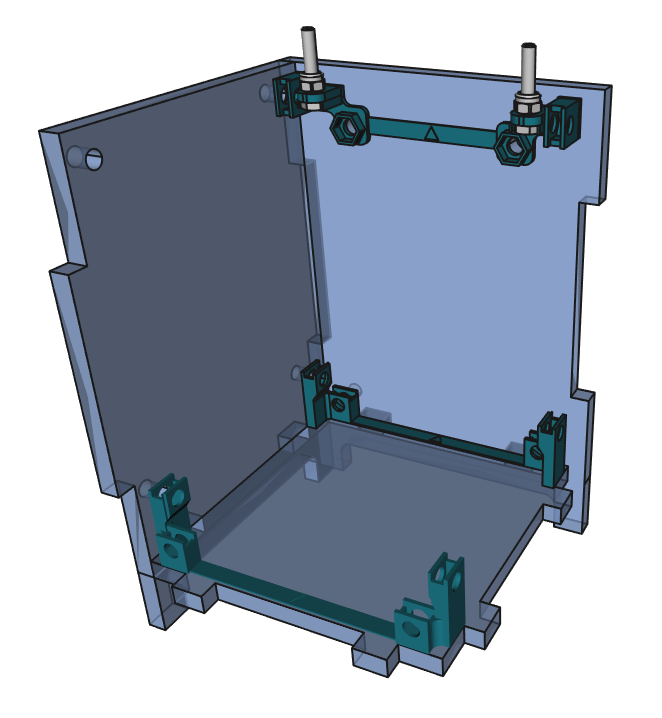
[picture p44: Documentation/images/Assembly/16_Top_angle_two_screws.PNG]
 <table> <tr> <td>  </td> <td> <ul>
        <li>Mount the <b>top bracket</b> (the one with the two steel screws) to the back side</li>
        <li>Use PP screws for connecting the parts</li>
      </ul> </td> </tr> </table>

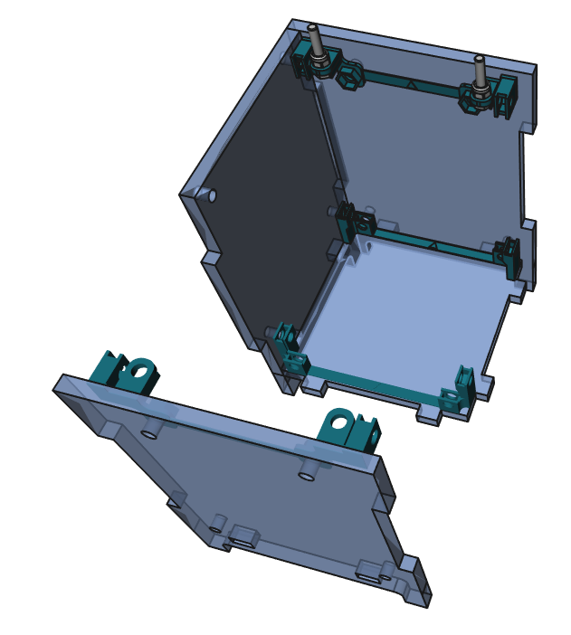
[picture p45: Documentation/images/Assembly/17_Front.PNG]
 <table> <tr> <td>  </td> <td> <ul>
        <li>Mount the other <b>top bracket</b> (the one without steel screws) to the front side using PP screws</li>
        <li>Don't mount the front part yet. Put it aside for now.</li>
      </ul> </td> </tr> </table>

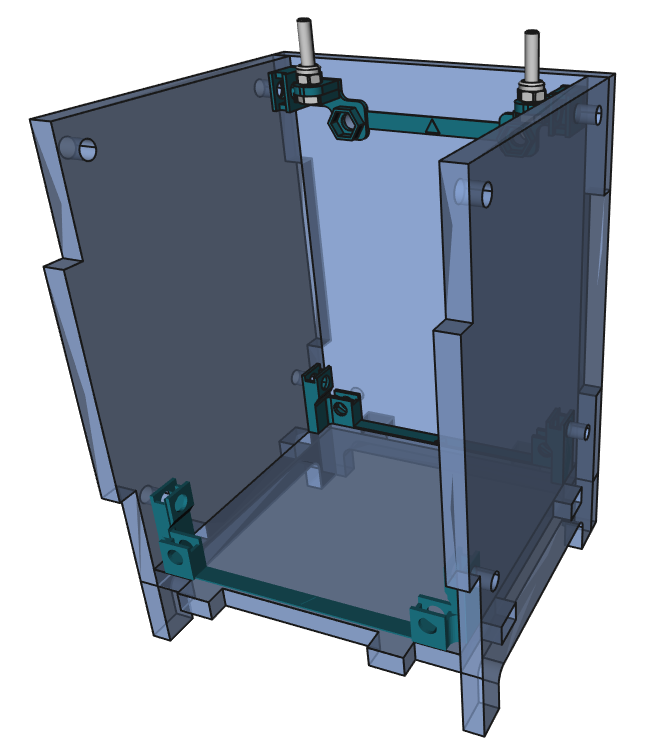
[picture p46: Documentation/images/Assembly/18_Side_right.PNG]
 <table> <tr> <td>  </td> <td> <ul>
        <li>Mount the right part to the structure using PP screws</li>
      </ul> </td> </tr> </table>

## Assembling the lid and the pump

- Put the 3D printed threaded adapter on top of the lid
- Make sure you put it on the correct side (if you prefer the other side to be visible, flip the lid)

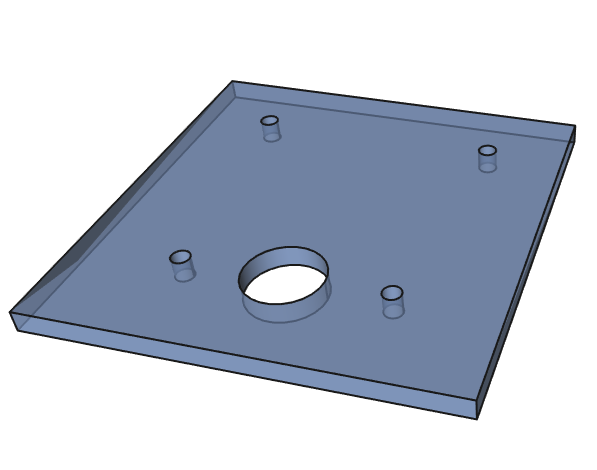
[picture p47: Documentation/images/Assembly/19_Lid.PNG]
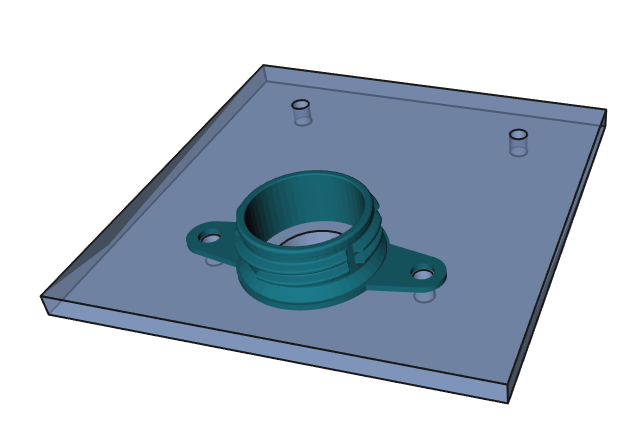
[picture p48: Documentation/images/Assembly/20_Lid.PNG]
 

- Use two M3 x 10 screws (PP) and two M3 nuts (PP) to mount it
- The nuts should be on the bottom

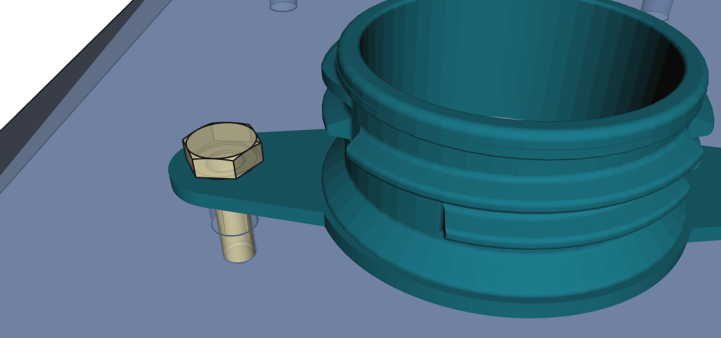
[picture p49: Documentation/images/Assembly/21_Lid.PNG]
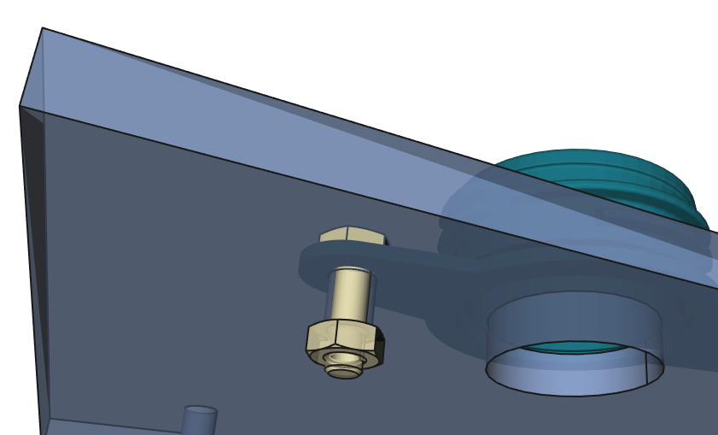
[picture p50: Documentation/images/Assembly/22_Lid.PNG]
 

> ____________________________
>
> ⚠ The following steps may vary a bit depending on the pump you have purchased
>
> ____________________________

- Screw the pump on the threaded adapter

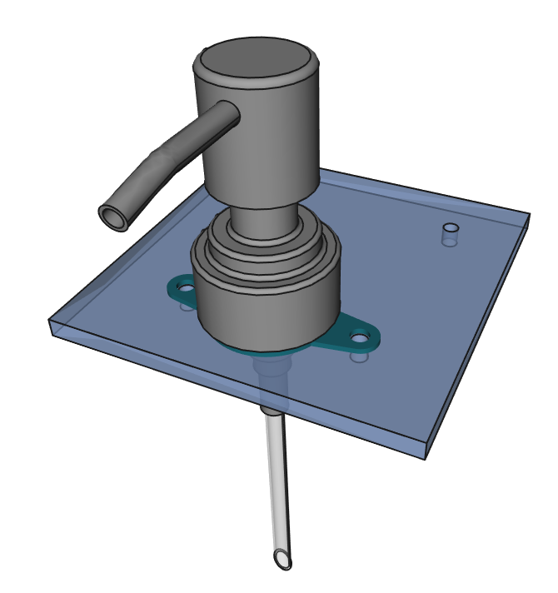
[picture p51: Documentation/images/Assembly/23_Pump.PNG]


- The next picture shows how the pump with the tube should fit in the dispenser
- The tube may be too long, so now is a good time to test it and cut the tube to the correct length (continue reading below)

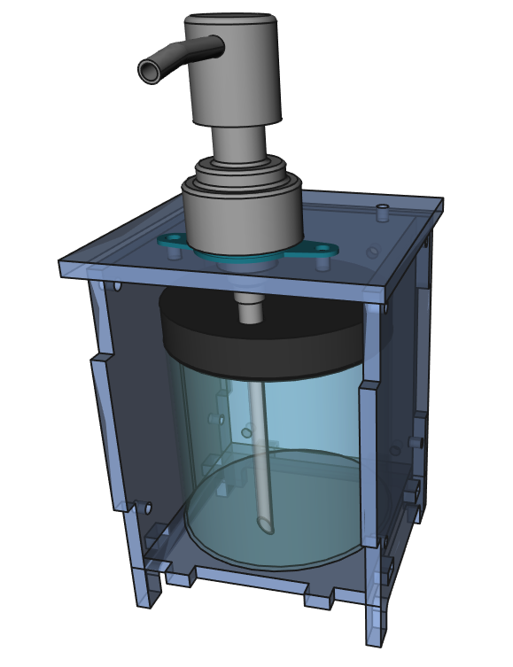
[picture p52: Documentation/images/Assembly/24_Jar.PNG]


- Put the lid with the pump and tube on the dispenser structure (leave the jar away for now), test the tube length and cut it to the right length
- Cut the tube at an 45° angle to retain suction strenght (see picture below)
- Be careful not to cut off too much. You can still shorten the tube a bit if it's still too long

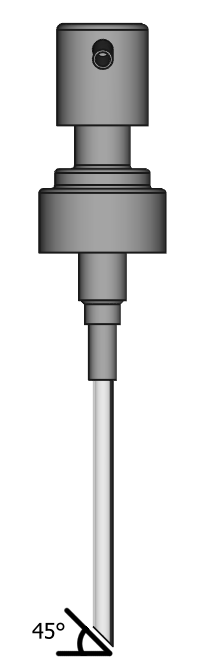
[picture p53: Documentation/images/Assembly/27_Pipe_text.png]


## Drilling a hole in the jar

- At first you need to find the right spot for the borehole. There are several ways to do it.
  - You can place the jar with the lid in the structure and put the lid with the pump (remove the tube first) on top and mark the spot where the pump pipe hits the lid
  - You can also use the 3D printed drilling template if it fits your jar size and mark the drilling spot
  - If you want to punch a little hole in the drilling spot, don't use a hammer or at least be careful, because a plastic lid could crack

  

- Measure the diameter of the pump pipe and choose a drill bit that matches the pipe.
   - The hole can match exactly or it can be a bit wider than the pipe (for example, for a 7 mm pipe you can drill an 8 mm hole)
- Place the jar with the drilled lid in the structure and test if it fits with the pump and the tube

> Optional: You can attach some sort of handle (e.g. a nylon string put through two little holes) to the top of the jar lid to make it easier to remove from the structure

## Final assembly steps

- Mount the front plate to the structure
- Check if all PP screws are attached (16 screws in the four side walls, 2 screws on the lid, not shown in the picture)
  - Tighten them with the 3D printed wrench
- Put the jar with the lid in the dispenser structure 

 

- Put the lid with the pump on top of the dispenser structure
- Fix the two metal screws with two wingnuts
- For refilling the dispenser, unscrew the wingnuts. Be careful to not lose them in the sink (move the dispenser away from the sink before you unscrew the wingnuts)
- Have fun with your dispenser! :)

> For further modding and upgrading, see the [documentation](Introduction.md), section Modding and upgrading



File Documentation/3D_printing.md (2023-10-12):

> Back to [documentation introduction](Introduction.md)

# 3D printing

You can download all the STL files for 3D printing [here](../3D_printing).

If you want to modify the 3D printed parts, you can download the [FreeCAD design file](../CAD), modify the parts in [FreeCAD](https://www.freecad.org/) and export the bodies via File -> Export, choosing "STL Mesh" as file format.

## Part list

This list shows you which parts to print and in what quantity:

| Quantity  | Part (STL file name) | Type |
|---|---|---|
| 2 | Angle_bracket_bottom | Part |
| 2 | Angle_bracket_top | Part |
| 1 | Adapter_for_pump | Part |
| 1 | Wrench | Tool |
| 1 | Drilling_template | Tool |

- The angle brackets (bottom/top) and the adapter are parts of the product
- The wrench and drilling template are tools that are not part of the product, but will help you in the making and assembly process



## Filament material

Printing with PLA was tested and worked well. Other materials might work, too.

This filament was used for the prototype: https://www.3djake.de/formfutura/reform-rpla-turkish-blue

## Printing settings

Here are some recommended printing settings. 3D printing was tested with a Prusa MK3S with PLA. You can apply similar settings to other printers.

- **Print settings (Prusa slicer):** 0.15 mm QUALITY
- **Layer height:** 0.15 mm
- **First layer height:** 0.2 mm
- **Infill:** 15 %
- **Support material:** no supports needed

Printing time with these settings and printer: 1 h 55 min

## Postprocessing

Make sure to remove all stringing from the 3D printed parts (e.g. by using some small scissors), especially inside the pockets for the nuts, to make sure the nuts fit in well.

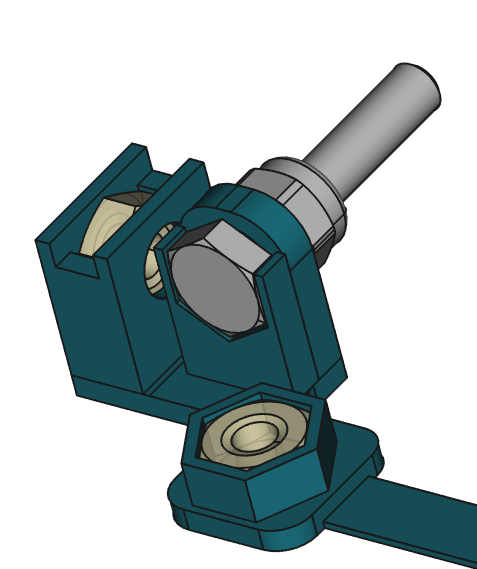
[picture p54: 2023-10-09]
Documentation/images/Assembly/11_Angle_top_screw.PNG

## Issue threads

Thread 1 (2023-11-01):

Suggestion: Make hole diameter parametric

hkienle, 2023-11-01:
The hole diameter is hard-coded to 4mm, but for M3 screws it could be tighter. Either way, I think it would be good to make this value parametric by putting it in the spreadsheet.
